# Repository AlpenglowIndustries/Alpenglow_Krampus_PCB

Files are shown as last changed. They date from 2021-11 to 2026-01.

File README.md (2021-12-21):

# Alpenglow_Krampus_PCB
Kicad files for Merry Krampus PCB including schematic and assembly pdfs.

Merry Krampus is available on our website and Tindie, in an assembled version, Hacker Challenge version, and Just the Board version.
https://www.alpenglowindustries.com/store/p23/krampus.html#/
https://www.tindie.com/products/alpenglow/merry-krampus/

Instructions:
https://www.alpenglowindustries.com/krampus

## Notes for Next Revision
1. add series programming resistors
2. change 10k to 100k
3. add polarity mark to programming conn
4. make programming conn pattern bigger
5. add text to switches

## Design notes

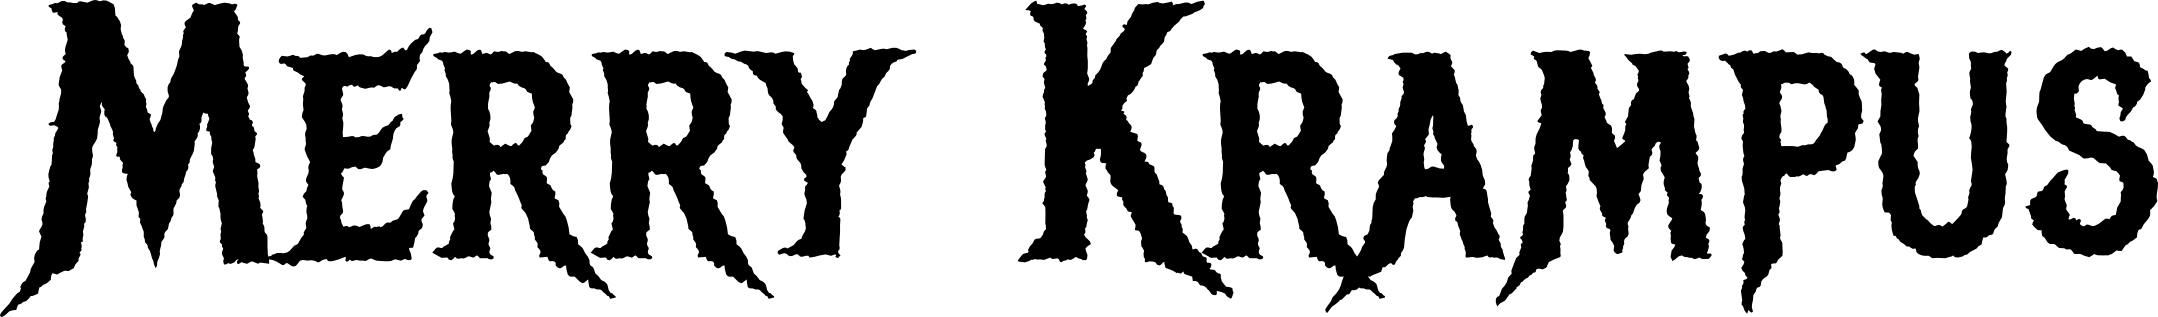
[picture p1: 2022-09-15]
Artwork/KRP board name with font.png

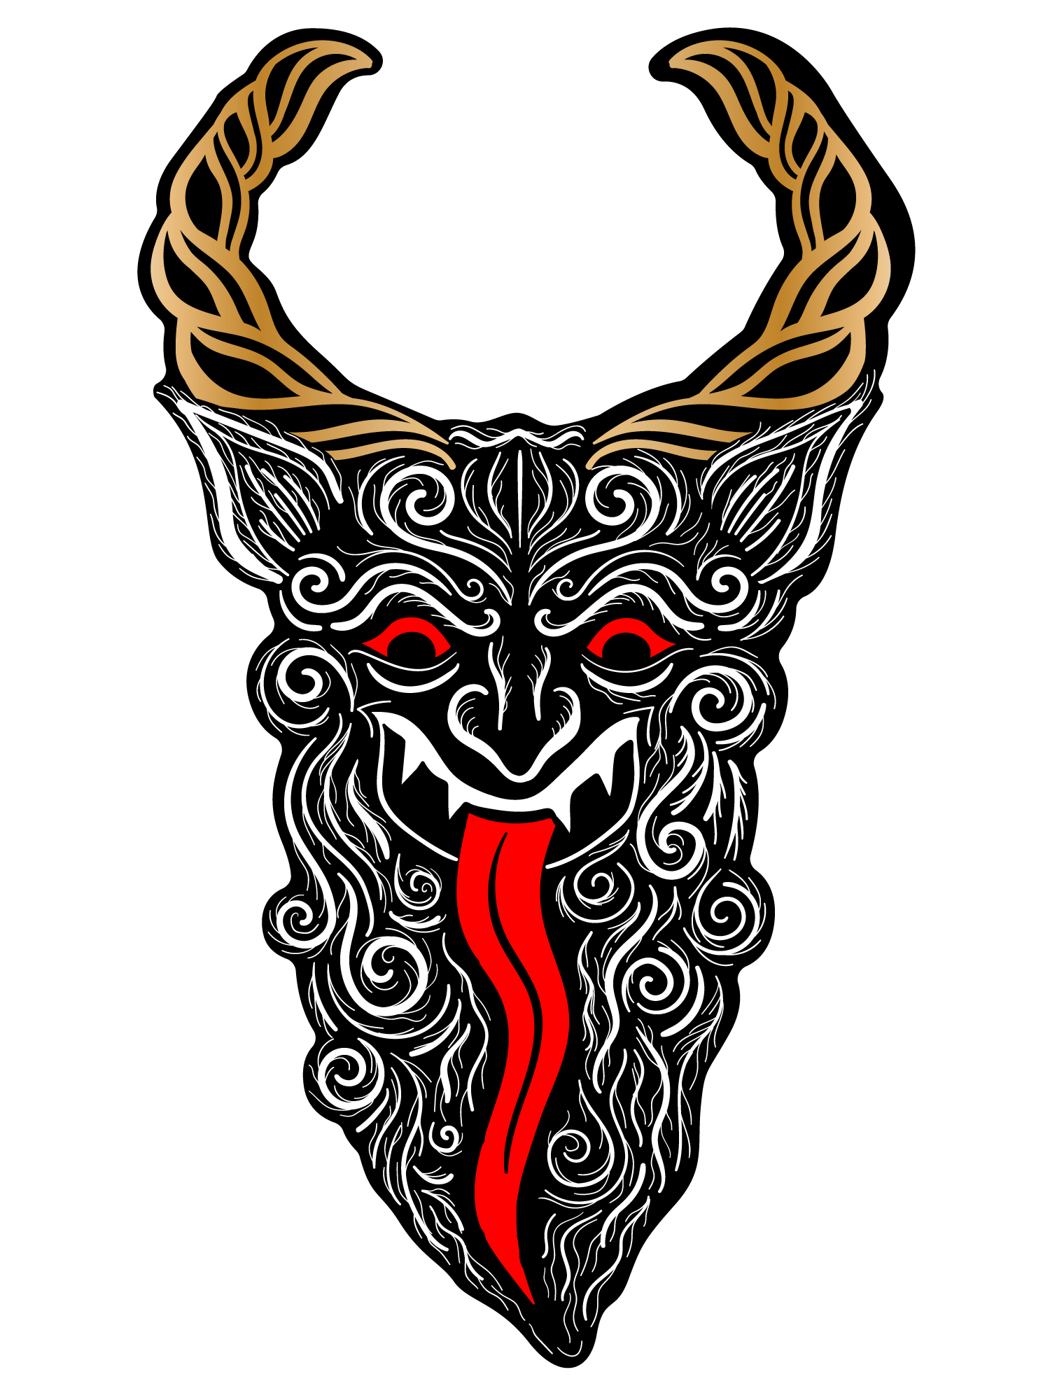
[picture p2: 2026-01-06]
Artwork/krampus-v1.jpg

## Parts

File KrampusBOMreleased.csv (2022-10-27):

Id | Designator | Package | Qty kit | Qty PCB | Designation | Manufacturer | Manufacturer Part Number
1 | SW1, SW2 | SW_SPDT_PCM12 | 3 | 2 | SW_SPDT | Daier | MSK-12C02
2 | BT1 | BatteryHolder_CR2032_SMT | 1 | 1 | CR2032 | Hongkong RTL | BK-912
3 | D3,D4,D5,D6,D2,D1 | LED_1204_RTA_2P | 7 | 6 | LED | Lite-On | LTST-S110KRKT
4 | R3,R8 | R_1206_3216Metric_Pad1.30x1.75mm_HandSolder | 3 | 2 | 100k | Stackpole | RMCF1206FT100K
5 | R1,R2,R5,R6,R7,R4 | R_1206_3216Metric_Pad1.30x1.75mm_HandSolder | 7 | 6 | 220 | Stackpole | RMCF1206FT220R
6 | U1 | SOT-23-6_Handsoldering | 1 | 1 | ATtiny4-TS-PROG | Microchip | ATTINY4-TSHR
7 | C1 | C_1206_3216Metric_Pad1.33x1.80mm_HandSolder | 2 | 1 | 0.1 | Samsung | CL31B104KBCNNNC
8 | Q1,Q2 | SOT-23-3 | 3 | 2 | Q_NMOS_GSD | NXP | 2N7002P,215
 |  | PCB | 1 | 1
 |  | All kits:
 |  | jump rings, brass, 10mm round, 8mm ID, 18 gauge | 4 | 0 |  | Fire Mtn Gems | H20-5304FD
 |  | chain, 3mm x 5mm twisted oval links, brass | 1 | 0
 |  | CR2032 battery | 1 | 0 |  | PKCell
 |  | sticky pin | 1 | 0
 |  | magnet, 10mm x 3mm rare earth | 1 | 0
 |  | Hacker Challenge Kit:
 |  | USBasp Programmer (updated for TPI) | 1 | 0
 |  | Pogo PCB Kit | 1 | 0 |  | Alpenglow Ind | ISP-0002

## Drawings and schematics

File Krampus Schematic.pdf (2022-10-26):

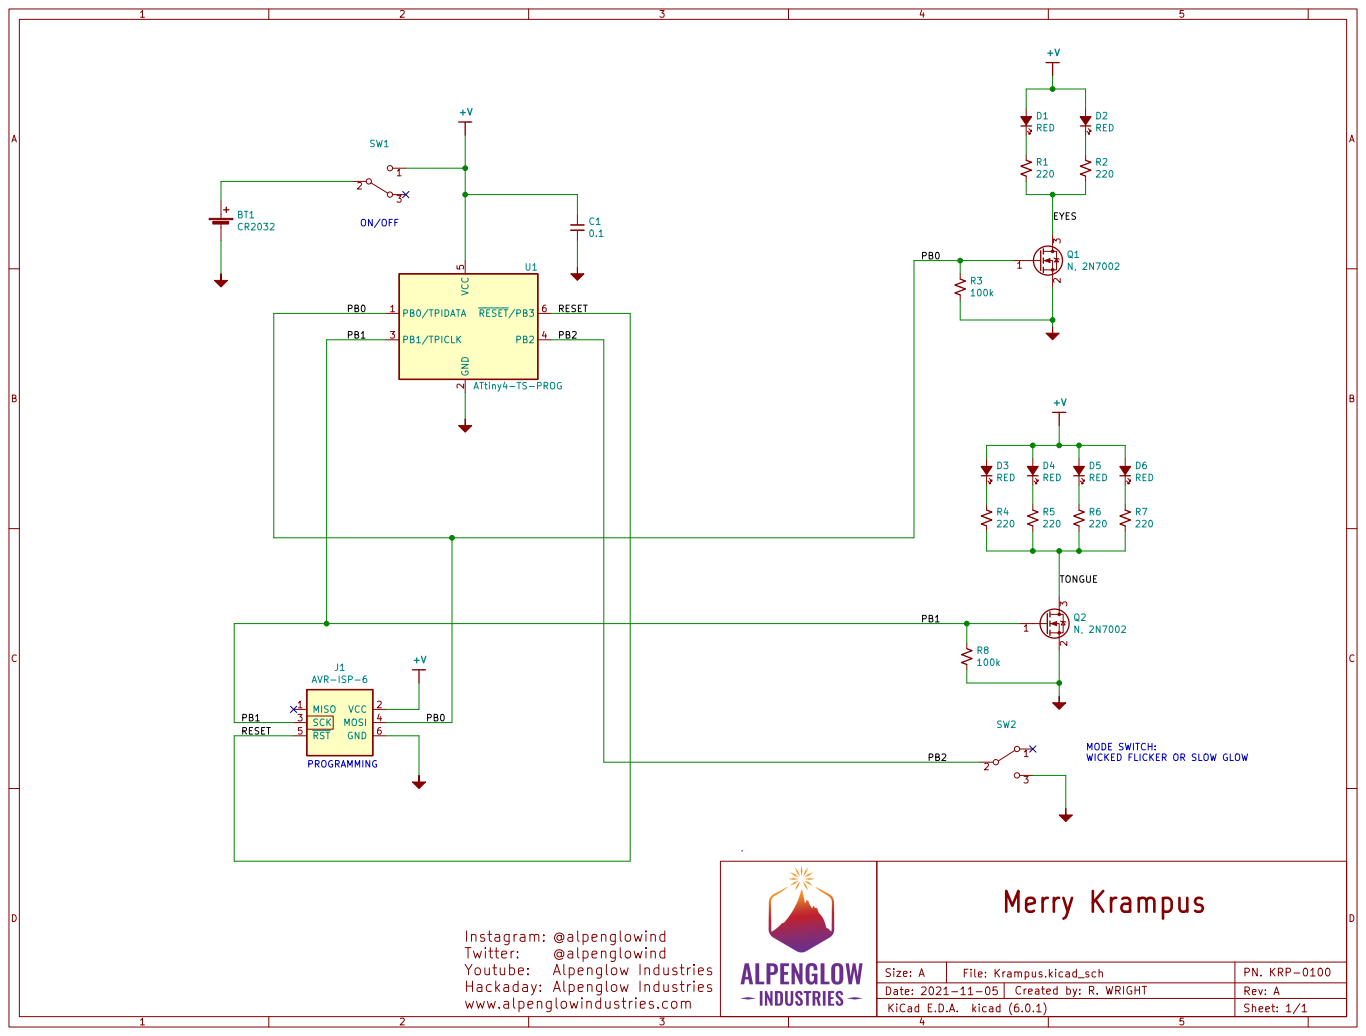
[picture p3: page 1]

www.alpenglowindustries.com Alpenglow Industries | Alpenglow Industries | Sheet: 1/1 Merry Krampus

Size: A
Date: 2021-11-05 KiCad E.D.A. kicad (6.0.1) | | Rev: A

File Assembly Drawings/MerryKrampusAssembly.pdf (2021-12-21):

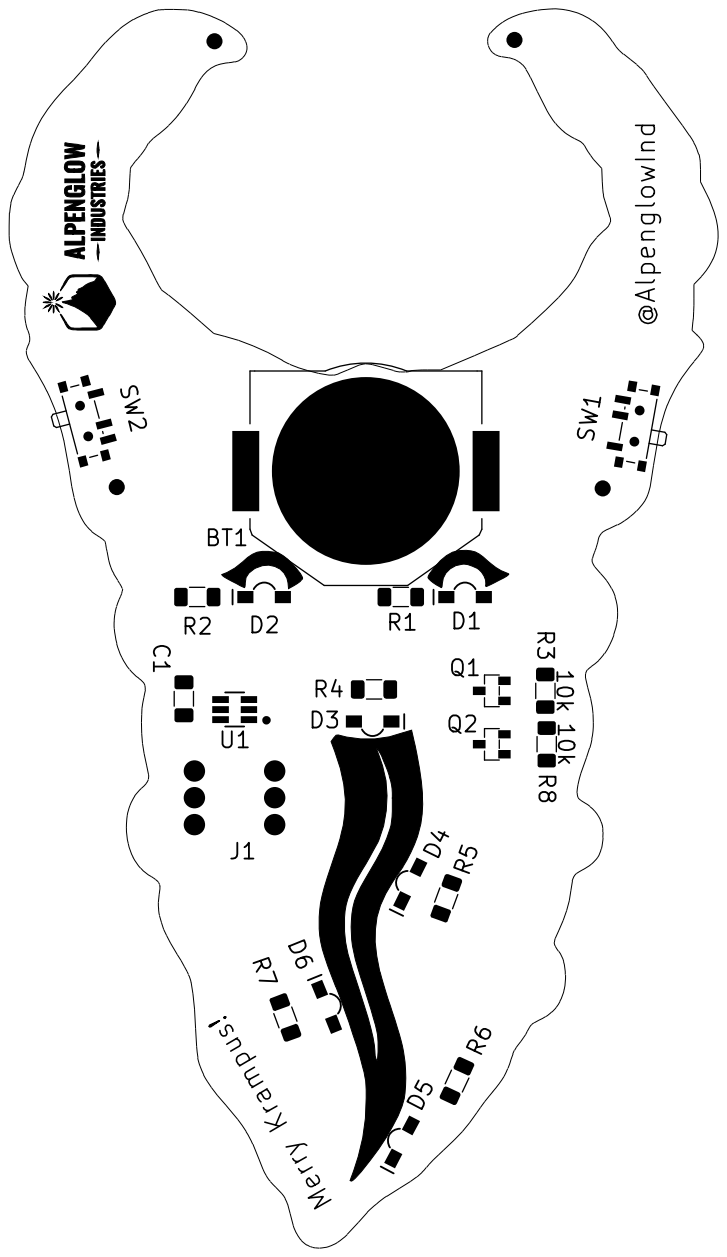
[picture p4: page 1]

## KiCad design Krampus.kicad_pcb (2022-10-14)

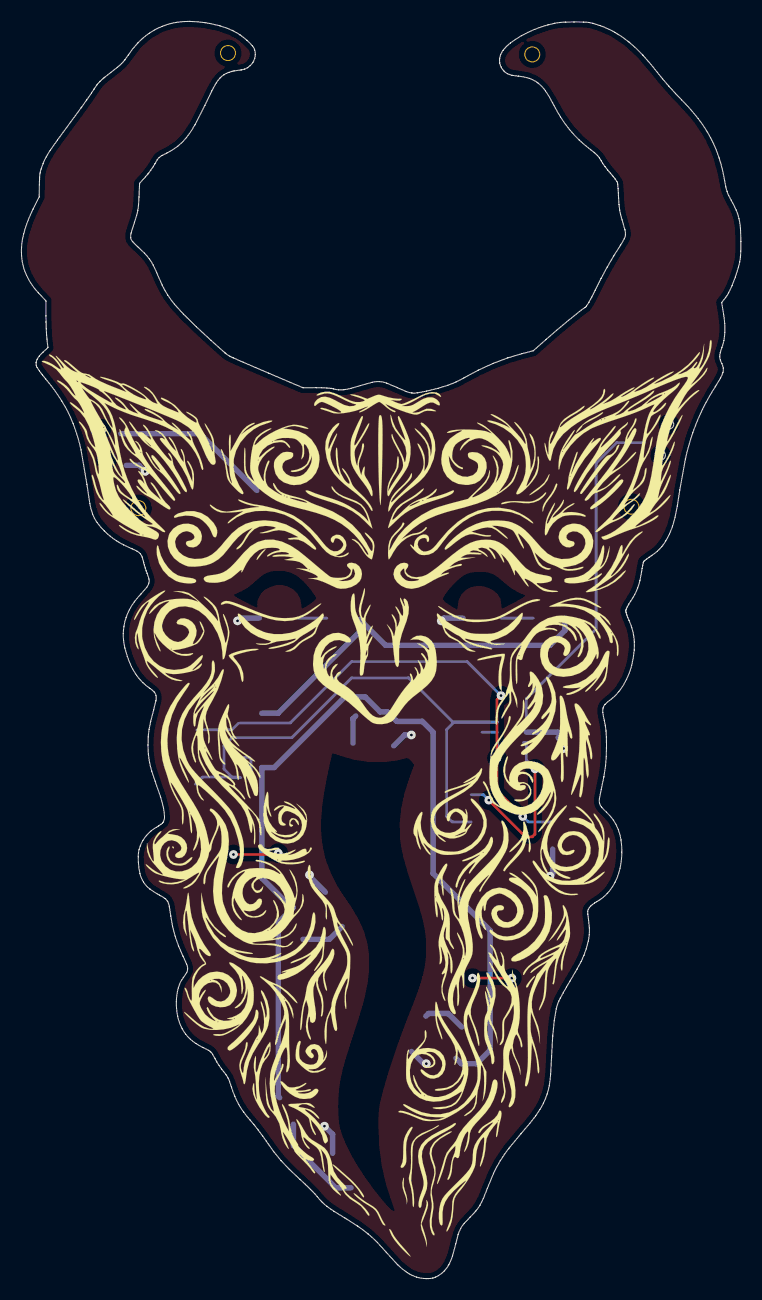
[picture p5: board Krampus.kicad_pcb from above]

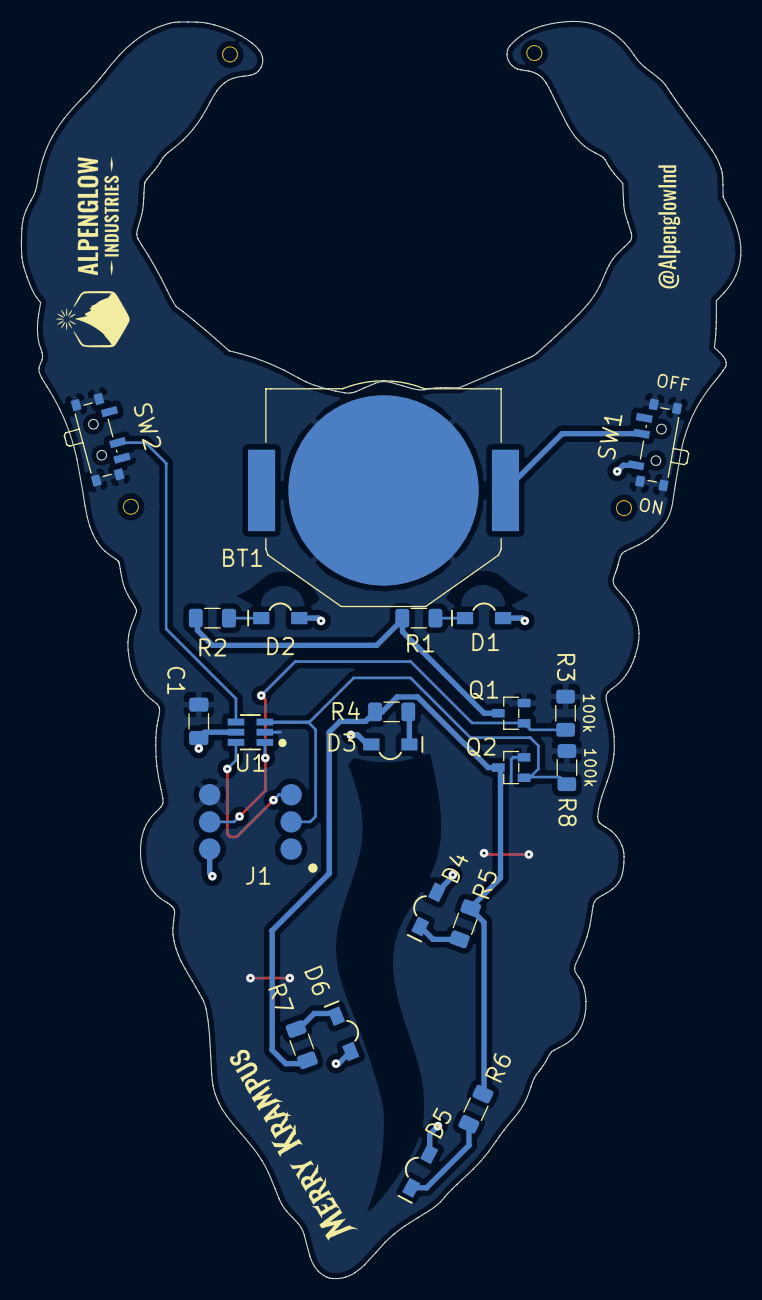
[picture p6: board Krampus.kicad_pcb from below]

Board: 2 copper layers, 67.3 x 117.5 mm, 27 parts (23 on the bottom side), 15 nets.

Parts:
BT1: Battery_Cell; BatteryHolder_CR2032_SMT
C1: 0.1; C_1206_3216Metric_Pad1.33x1.80mm_HandSolder
D1, D2, D3, D4, D5, D6: LED; LED_1204_RTA_2P
G2: LOGO; Red
G3: LOGO; Red-back
G4: LOGO; WhitenoMouth
G5: LOGO; GoldwithTeeth
G6: LOGO; Alpenglow_Logo_Horiz_8mm
J1: AVR-ISP-6; CONN-ISP-POGO-SMT
Q1, Q2: Q_NMOS_GSD; SOT-23-3
R1, R2, R4, R5, R6, R7: 470; R_1206_3216Metric_Pad1.30x1.75mm_HandSolder
R3, R8: 100k; R_1206_3216Metric_Pad1.30x1.75mm_HandSolder
SW1: SW_SPDT_Flipped; SW_SPDT_PCM12
SW2: SW_SPDT; SW_SPDT_PCM12
U1: ATtiny4-TS-PROG; SOT-23-6_Handsoldering

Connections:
+V: C1.1, D1.2, D2.2, D3.2, D4.2, D5.2, D6.2, J1.2, SW1.1, U1.5
/EYES: Q1.3, R1.2, R2.2
/PB0: J1.4, Q1.1, R3.1, U1.1
/PB1: J1.3, Q2.1, R8.1, U1.3
/PB2: SW2.2, U1.4
/RESET: J1.5, U1.6
/TONGUE: Q2.3, R4.2, R5.2, R6.2, R7.2
GND: BT1.2, C1.2, J1.6, Q1.2, Q2.2, R3.2, R8.2, SW2.3, U1.2
unnamed: BT1.1, SW1.2
unnamed: D1.1, R1.1
unnamed: D2.1, R2.1
unnamed: D3.1, R4.1
unnamed: D4.1, R5.1
unnamed: D5.1, R6.1
unnamed: D6.1, R7.1

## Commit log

2021-11-08 Initial layout, traces routed but planes not poured yet.
    [Krampus.kicad_pcb, Krampus.sch]
2021-11-09 Added copper pours and keepout areas for tongue and eyes. Everything done except edge cuts and revised mouth (want it to be gold)
    [Krampus - Copy.kicad_pcb, Krampus.kicad_pcb, Krampus.sch]
2021-11-11 Added board outline, Changed teeth to gold, other tweaks and adjustments to layout
    [Krampus.kicad_pcb]
2021-11-13 generated gerbers, other fab files, and BOM
    [Krampus-B_Cu.gbr, Krampus-B_Mask.gbr, Krampus-B_Paste.gbr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]
2021-11-18 deleted old export
    [Krampus.xlsx]
2021-12-21 updated sch for final values, added pdfs for schematic and assembly, updated readme for next version notes, added template to schematic, added BOM
    [Krampus.kicad_pcb, Krampus.sch, KrampusBOMreleased.xlsx]
2021-12-21 moved gerbers into a folder for better clarity
    [Krampus-B_Cu.gbr, Krampus-B_Mask.gbr, Krampus-B_Paste.gbr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]
2022-09-15 Updated board name with font, updated @alpenglowind to oswald font
    [Krampus.kicad_pcb]
2022-10-14 Changed 10k resistor value to 100k
    [Krampus.kicad_pcb]
2022-10-14 Added On OFF labels and pin1 mark on back silkscreen
    [Krampus.kicad_pcb]
2022-10-26 Assembly drawings, Schematic
2022-10-26 Added title block, updated schematic PDF
    [Krampus.kicad_sch]
2022-10-27 updated BOM
    [KrampusBOMreleased.xlsx]
2022-10-27 Changed BOM to CSV file
    [KrampusBOMreleased.xlsx]
2022-10-27 Updated gitignore, changed BOM to CSV file
    [KrampusBOMreleased.csv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]
